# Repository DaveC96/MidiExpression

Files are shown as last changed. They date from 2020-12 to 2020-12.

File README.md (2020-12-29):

# MidiExpression
A hardware unit to add MIDI control to any device that takes an expression pedal input.

This is based on the Arduino Nano, and so only supports DIN MIDI. This project could easily be replicated with a Teensy or similar for USB support.

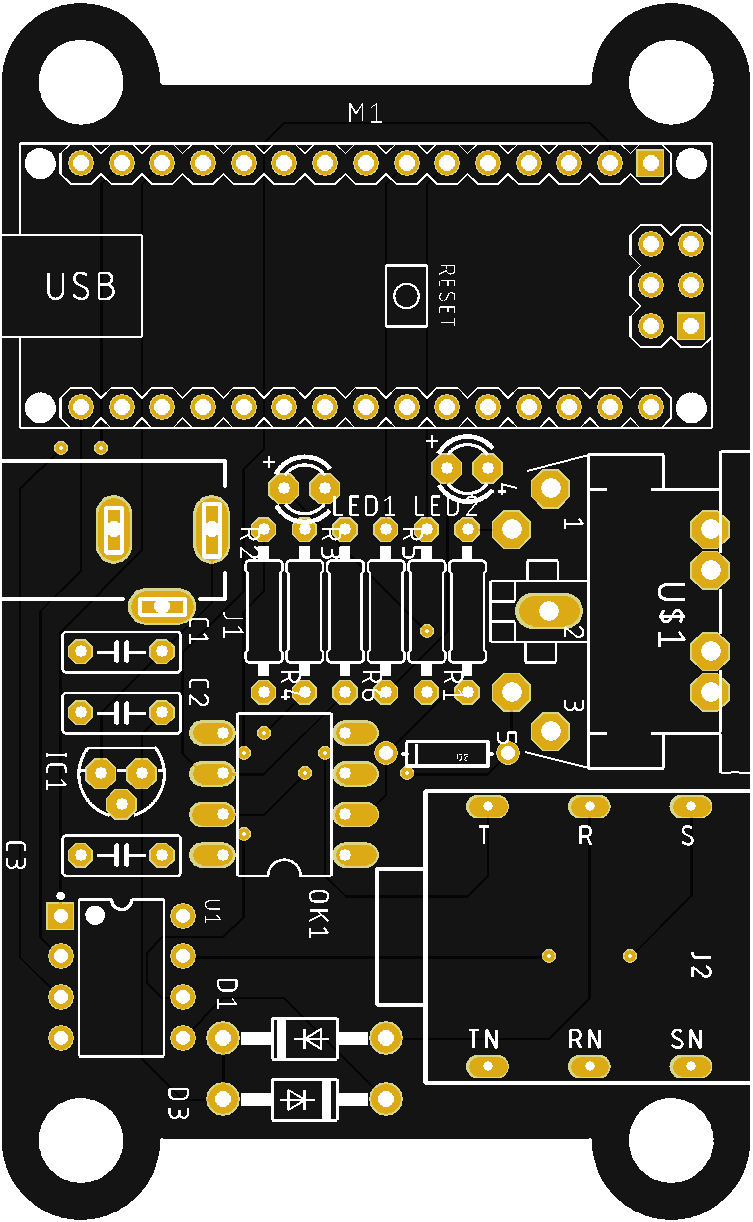
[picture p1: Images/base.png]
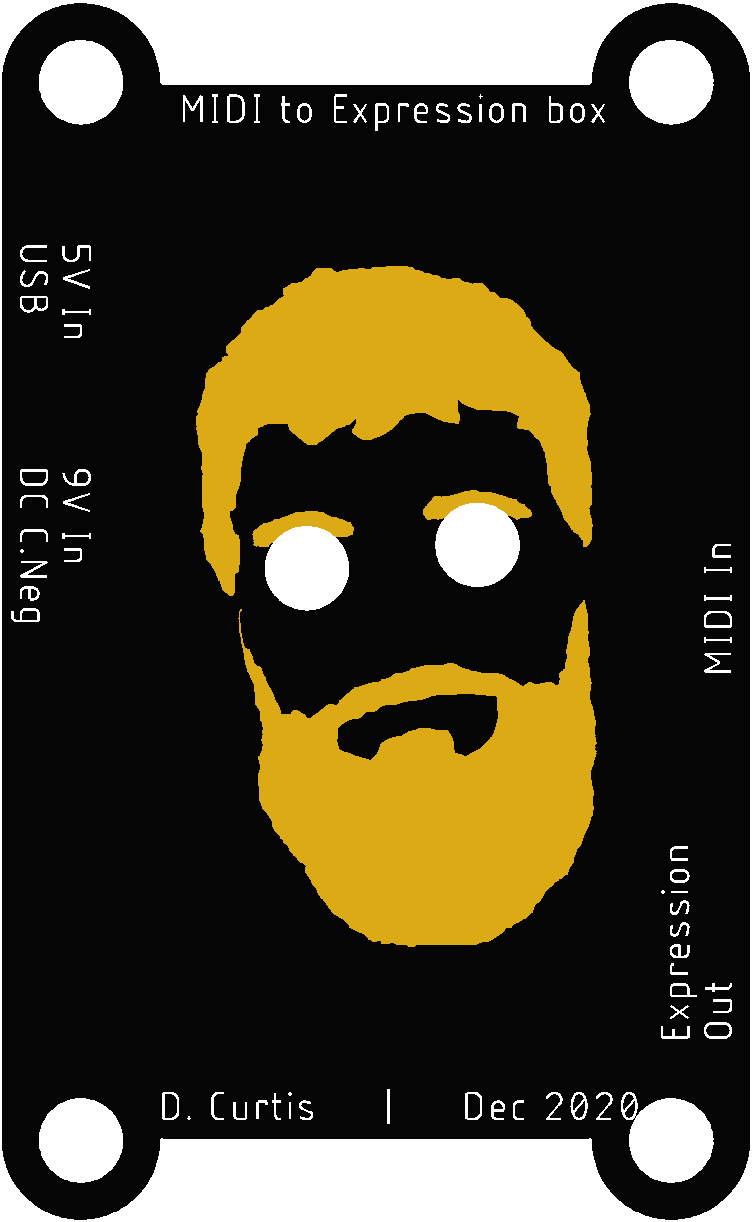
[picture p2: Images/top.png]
 

The board can be powered by:
- USB directly to the Nano
- DC barrel (centre-negative to work with guitar pedalboard PSUs)
- (Speculatively) Directly from the reference voltage on the expression input

-----

## Usage

Upon being powered on, the device will attempt to read any persistent settings. If none are found, it resets to these defaults:

| Param | Value |
| :--- | :--- |
| Channel | 0 (omni) |
| CC | 4 |
| Min value | 0 |
| Max value | 127 |

These can be changed by sending a SysEx message in the following manner:

`[sysex header (0xF0)] [manufacturer ID (0x00)] [channel (0-16)] [CC] [min] [max] [sysex terminator (0xF7)]`

For example, to set channel **12**, CC **42**, with a range of **18**-**99**, the message would be (hex):

`F0 00 0C 2A 12 63 F7`

When receiving a valid sysex config message, the device will reboot to adopt the new parameters.
A hard flash reset for emergenciees can be performed by sending the following (very original) sysex message:

`F0 00 DE AD F7`

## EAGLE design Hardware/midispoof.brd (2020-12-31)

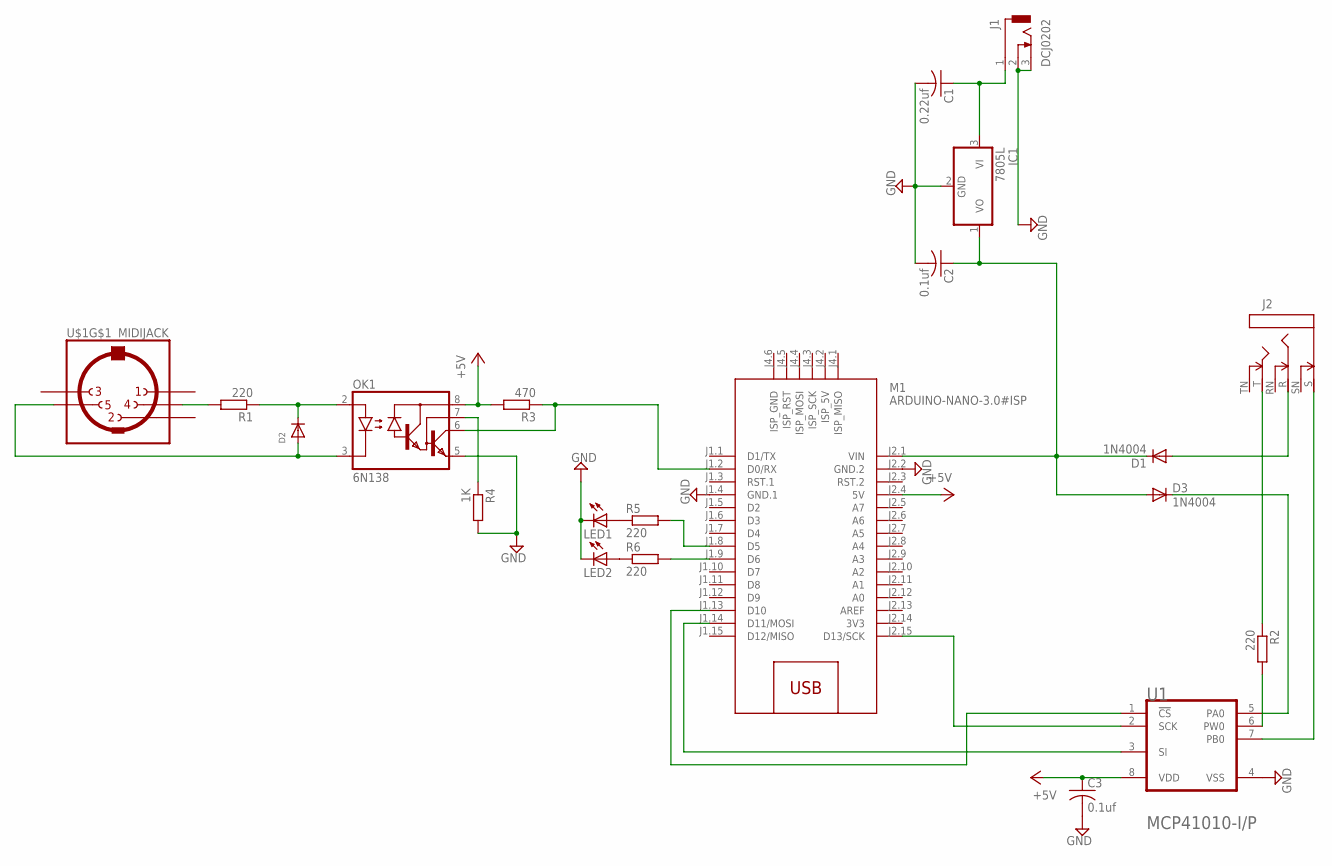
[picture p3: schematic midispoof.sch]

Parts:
C1: 0.22uf; C050-025X075
C2, C3: 0.1uf; C050-025X075
D1, D3: 1N4004; DO41-10
D2: DIODEDO-1N4148; DO-1N4148
IC1: 7805L; TO92
J1: DCJ0202
J2: STEREOSWS; NMJ6HC-S
LED1, LED2: LED3MM
M1: ARDUINO-NANO-3.0#ISP
OK1: 6N138; DIL08
R1, R2, R5, R6: 220; 0207/10
R3: 470; 0207/10
R4: 1K; 0207/10
U1: MICROCHIP_MCP41010-I-PMICROCHIP_MCP41010-I-P_0_0; MICROCHIP_MCP41010-I-P_0
U$1: MIDIJACK; CP-2350

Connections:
3V3: M1.J2.14 (3V3)
+5V: C3.1, M1.J2.4 (5V), OK1.8 (VCC), R3.2, U1.8 (VDD)
GND: C1.2, C2.2, C3.2, IC1.2 (GND), J1.2, J1.3, LED1.K (C), LED2.K (C), M1.J1.4 (GND.1), M1.J2.2 (GND.2), OK1.5 (GND), R4.2, U1.4 (VSS)
unnamed: M1.J2.15 (D13/SCK), U1.2 (SCK)
unnamed: C1.1, IC1.3 (VI), J1.1
unnamed: M1.J1.14 (D11/MOSI), U1.3 (SI)
unnamed: LED1.A, R5.1
unnamed: R1.2, U$1.4
unnamed: M1.J1.13 (D10), U1.1 (!CS!)
unnamed: D1.A, J2.R
unnamed: D3.C, U1.5 (PA0)
unnamed: J2.S, U1.7 (PB0)
unnamed: J2.T, R2.1
unnamed: R2.2, U1.6 (PW0)
unnamed: D2.C, OK1.2 (A), R1.1
unnamed: D2.A, OK1.3 (C), U$1.5
unnamed: M1.J1.2 (D0/RX), OK1.6 (VO), R3.1
unnamed: C2.1, D1.C, D3.A, IC1.1 (VO), M1.J2.1 (VIN)
unnamed: OK1.7 (VB), R4.1
unnamed: LED2.A, R6.1
unnamed: M1.J1.8 (D5), R5.2
unnamed: M1.J1.9 (D6), R6.2

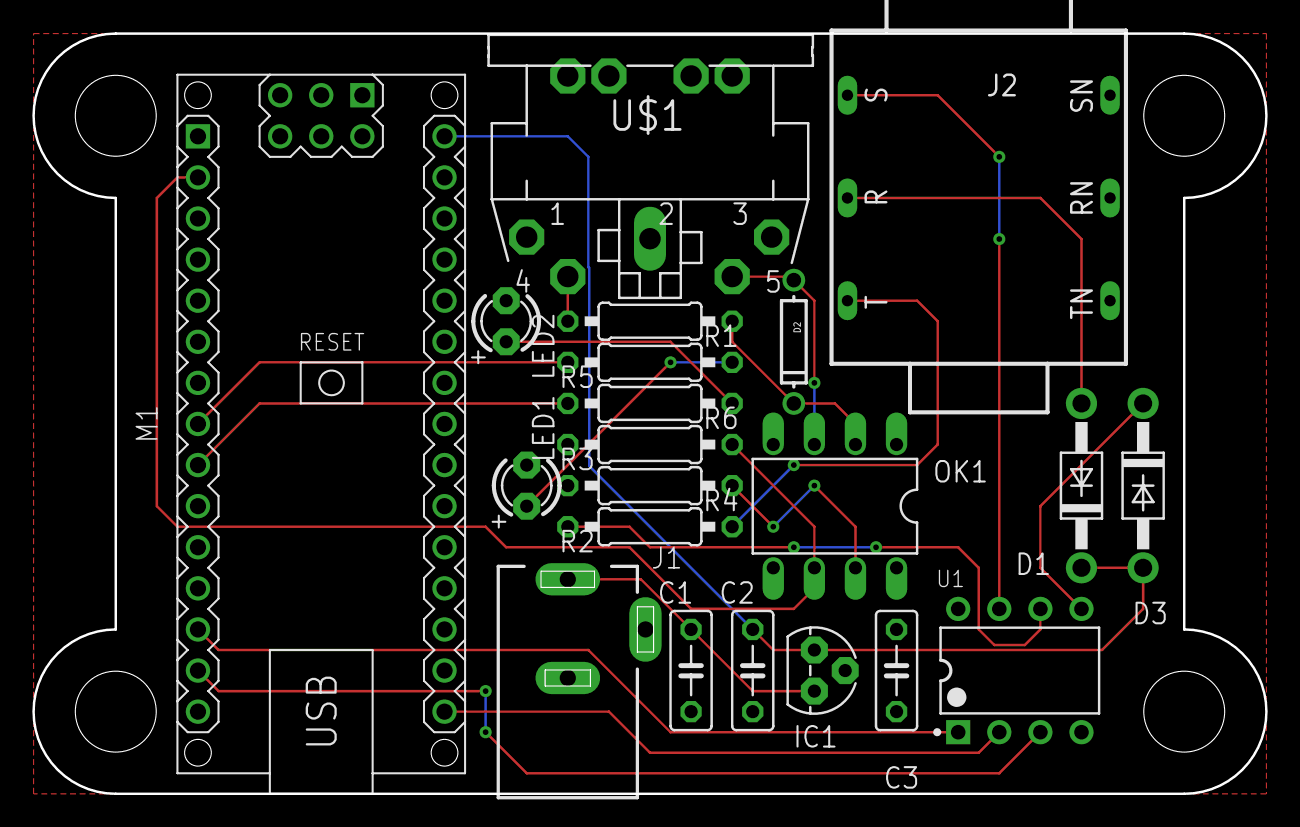
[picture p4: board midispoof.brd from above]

Board: 2 copper layers, 76.2 x 47.0 mm, 21 parts (0 on the bottom side), 21 nets.

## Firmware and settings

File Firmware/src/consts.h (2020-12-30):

#ifndef CONSTS_H
#define CONSTS_H

// This is just some arbitrary byte pattern we can use to know that the flash is valid.
// In this case, it's probably longer than the actual data. Oh well.
// ATmega128 has 512 whole bytes of EEPROM, so we should be ok.
#define FLASH_OK_TOKEN      (char*)"Elephant"
#define LEN_FLASH_OK_TOKEN  8

// EEPROM address for the app config to be stored to / recalled from
#define FLASH_OFFSET_APPCONFIG 0

// Used to validate arguments for AppConfig setters
#define MIDI_MAX        127
#define SYSEX_HEADER    0xF0
#define SYSEX_FOOTER    0xF7
#define SYSEX_MFR       0x00

// Safe defaults for AppConfig::_loadPanic() when FLASH_OK_TOKEN turns out to be uncharacteristically not ok
#define DEFAULT_CHANNEL 0           // MIDI_CHANNEL_OMNI -- but I don't really want to include MIDI.h in here...
#define DEFAULT_CC      4           // "Foot controller"
#define DEFAULT_MIN     0
#define DEFAULT_MAX     MIDI_MAX

// HARDWARE ================================================
#define PIN_LEFT_EYE    6           // D3
#define PIN_RIGHT_EYE   7           // D4

#define SPI_DELAY_MS    100         // ...Long enough to pass the edge

#endif

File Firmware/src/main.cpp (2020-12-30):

#include <Arduino.h>
#include <MIDI.h>
#include "AppConfig.h"
#include "mcp4131.h"

static AppConfig* Config;
static mcp4131* DigitalPot;
MIDI_CREATE_DEFAULT_INSTANCE();

void onRecvSysex(byte* data, unsigned size);
void onRecvCC(byte channel, byte controller, byte val);
void(* resetFunc) (void) = 0;

void setup()
{
  // Init hardware:
  pinMode(LED_BUILTIN,    OUTPUT);
  pinMode(PIN_LEFT_EYE,   OUTPUT);
  pinMode(PIN_RIGHT_EYE,  OUTPUT);
  pinMode(PIN_SPI_SS,     OUTPUT);
  pinMode(PIN_SPI_MOSI,   OUTPUT);
  pinMode(PIN_SPI_SCK,    OUTPUT);

  SPI.begin();
  DigitalPot = new mcp4131(PIN_SPI_SS, PIN_SPI_MOSI, PIN_SPI_SCK);

  // Load config:
  Config = new AppConfig;
  loadFromFlash(Config);

  // Wake up the MIDI port
  MIDI.begin(Config->channel);
  MIDI.setHandleSystemExclusive(onRecvSysex);
  MIDI.setHandleControlChange(onRecvCC);

  digitalWrite(PIN_LEFT_EYE, HIGH);
  digitalWrite(PIN_RIGHT_EYE, HIGH);
}


void loop()
{
  MIDI.read();
}


void onRecvSysex(byte* data, unsigned int size)
{
  digitalWrite(PIN_LEFT_EYE, LOW);
  digitalWrite(PIN_RIGHT_EYE, LOW);
  digitalWrite(LED_BUILTIN, HIGH);

  if (data[0] != SYSEX_HEADER || data[1] != SYSEX_MFR || data[size] != SYSEX_FOOTER) {
    return;
  } else if ((size = 5) && (data[2] == 0xDE) && (data[3] == 0xAD)) {  // Nuke flash
    for (unsigned int i = 0; i < EEPROM.length(); i++) {
      // loadFromFlash() will recreate safe values on reboot, this is probably redundant.
      EEPROM.write(i, 0xFF); 
    }
    resetFunc();

  } else {  // Probably a config message, lets hope for the best
    Config->channel = data[2];
    Config->cc = data[3];
    Config->valueMin = data[4];
    Config->valueMax = data[5];
    storeToFlash(Config);
    
    resetFunc();
  }
}


void onRecvCC(byte channel, byte controller, byte val)
{
  if (channel == Config->channel && controller == Config->cc) {
    uint8_t pwm = val*2;
    analogWrite(PIN_LEFT_EYE, pwm);
    analogWrite(PIN_RIGHT_EYE, pwm);
    DigitalPot->writeValue(val);
  }
}

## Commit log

2020-12-30 SPI stuff
2020-12-31 Corrected missing supply flood fills on PCB layout
    [midispoof.brd, midispoof.sch]

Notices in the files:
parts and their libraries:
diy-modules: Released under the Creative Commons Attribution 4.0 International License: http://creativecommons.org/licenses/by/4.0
